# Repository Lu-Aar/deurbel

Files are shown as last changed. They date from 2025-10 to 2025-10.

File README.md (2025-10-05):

# deurbel
Making an ordinairy doorbell smart by having a notification through discord and ringing a klikaanklikuit chime.

When the doorbell is pressed there are three notifications:
- A mechanical chime
- A KlikAanKlikUit chime
- A Discord notification

There are also two extra inputs:
- A test button: Added to to test the doorbell functionality
- A mute switch: This can enable/disable the chimes

This project is fully designed in RUST no_std and it's designed to be used with a ESP32-WROOM-32.

## ToDo after clone
When this repo is cloned there is one step which has to be done before the code can be used.
Inside the bin folder the following file needs to be created:
global/mod.rs

This file should contain the following items:
``` rust
pub const WIFI_SSID: &str = "THE_SSID_TO_CONNECT_TO";
pub const WIFI_PASSWORD: &str = "THE_PASSWORD_OF_THE_SSID";
pub const DISCORD_WEBHOOK_URL: &str = "THE_URL_OF_THE_DISCORD_WEBHOOK_TO_USE";
pub const DISCORD_TTS: &str = false; // Set to true when to use Text To Speech
```

## PCB
The PCB was created in KiCad. It's a free opensource program for creating schematics and PCB's.
https://www.kicad.org/

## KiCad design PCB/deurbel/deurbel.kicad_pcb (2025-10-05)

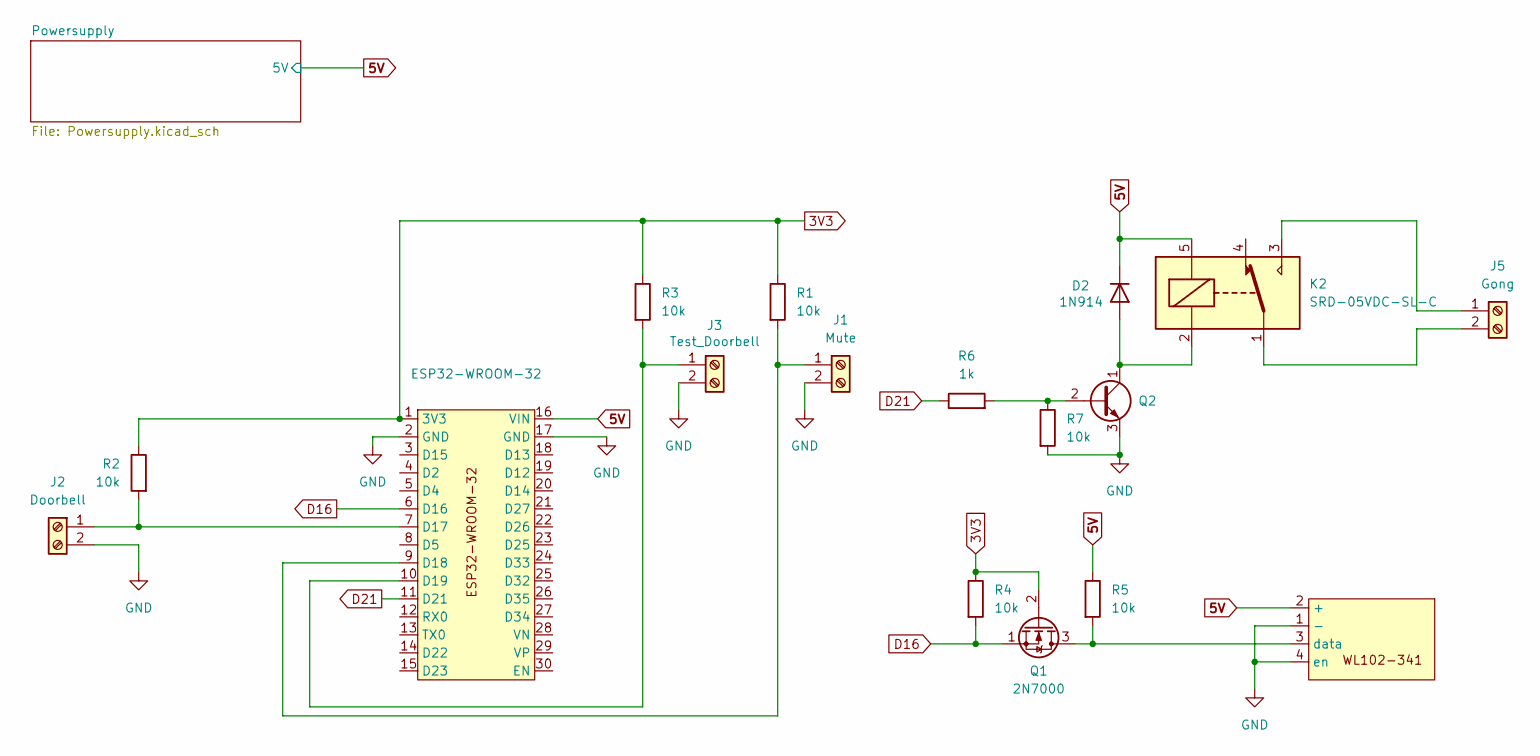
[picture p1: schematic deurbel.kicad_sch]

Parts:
D2: 1N914; D_DO-35_SOD27_P7.62mm_Horizontal
ESP32-WROOM-32: ESP32-WROOM-32
J1: Mute; TerminalBlock_Xinya_XY308-2.54-2P_1x02_P2.54mm_Horizontal
J2: Doorbell; TerminalBlock_Xinya_XY308-2.54-2P_1x02_P2.54mm_Horizontal
J3: Test_Doorbell; TerminalBlock_Xinya_XY308-2.54-2P_1x02_P2.54mm_Horizontal
J5: Gong; TerminalBlock_Xinya_XY308-2.54-2P_1x02_P2.54mm_Horizontal
K2: SRD-05VDC-SL-C; Relay_SPDT_SANYOU_SRD_Series_Form_C
Q1: 2N7000; TO-92_Inline
Q2: BC338; TO-92_Inline
R1, R2, R3, R4, R5, R7: 10k; R_Axial_DIN0204_L3.6mm_D1.6mm_P5.08mm_Horizontal
R6: 1k; R_Axial_DIN0204_L3.6mm_D1.6mm_P5.08mm_Horizontal
WL102-1: WL102-341

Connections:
3V3: ESP32-WROOM-32.1 (3V3), Q1.2 (G), R1.1, R2.1, R3.1, R4.1
5V: D2.1 (K), ESP32-WROOM-32.16 (VIN), K2.5, R5.1, WL102-1.2 (+); also elsewhere on the board
D16: ESP32-WROOM-32.6 (D16), Q1.1 (S), R4.2
D21: ESP32-WROOM-32.11 (D21), R6.1
GND: ESP32-WROOM-32.2 (GND), ESP32-WROOM-32.17 (GND), J1.2, J2.2, J3.2, Q2.3 (E), R7.2, WL102-1.1 (-), WL102-1.4 (en); also elsewhere on the board
unnamed: D2.2 (A), K2.2, Q2.1 (C)
unnamed: ESP32-WROOM-32.7 (D17), J2.1, R2.2
unnamed: ESP32-WROOM-32.9 (D18), J1.1, R1.2
unnamed: ESP32-WROOM-32.10 (D19), J3.1, R3.2
unnamed: J5.1, K2.3
unnamed: J5.2, K2.1
unnamed: Q1.3 (D), R5.2, WL102-1.3 (data)
unnamed: Q2.2 (B), R6.2, R7.1

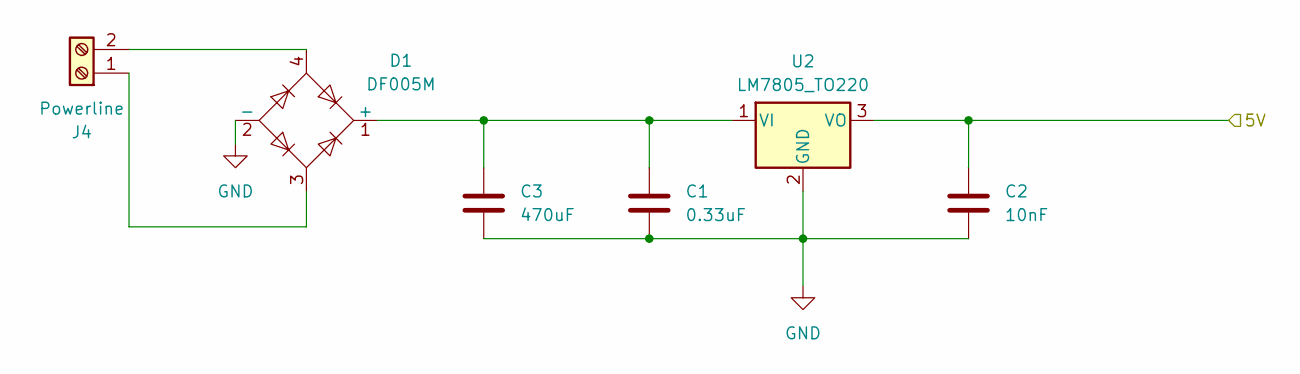
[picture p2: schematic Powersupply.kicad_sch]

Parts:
C1: 0.33uF; C_Disc_D4.3mm_W1.9mm_P5.00mm
C2: 10nF; C_Disc_D4.3mm_W1.9mm_P5.00mm
C3: 470uF; C_Disc_D4.3mm_W1.9mm_P5.00mm
D1: DF005M; Diode_Bridge_DIP-4_W7.62mm_P5.08mm
J4: Powerline; TerminalBlock_Xinya_XY308-2.54-2P_1x02_P2.54mm_Horizontal
U2: LM7805_TO220; TO-220-3_Vertical

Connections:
5V: C2.1, U2.3 (VO); also elsewhere on the board
GND: C1.2, C2.2, C3.2, D1.2 (-), U2.2 (GND); also elsewhere on the board
unnamed: C1.1, C3.1, D1.1 (+), U2.1 (VI)
unnamed: D1.3, J4.1
unnamed: D1.4, J4.2

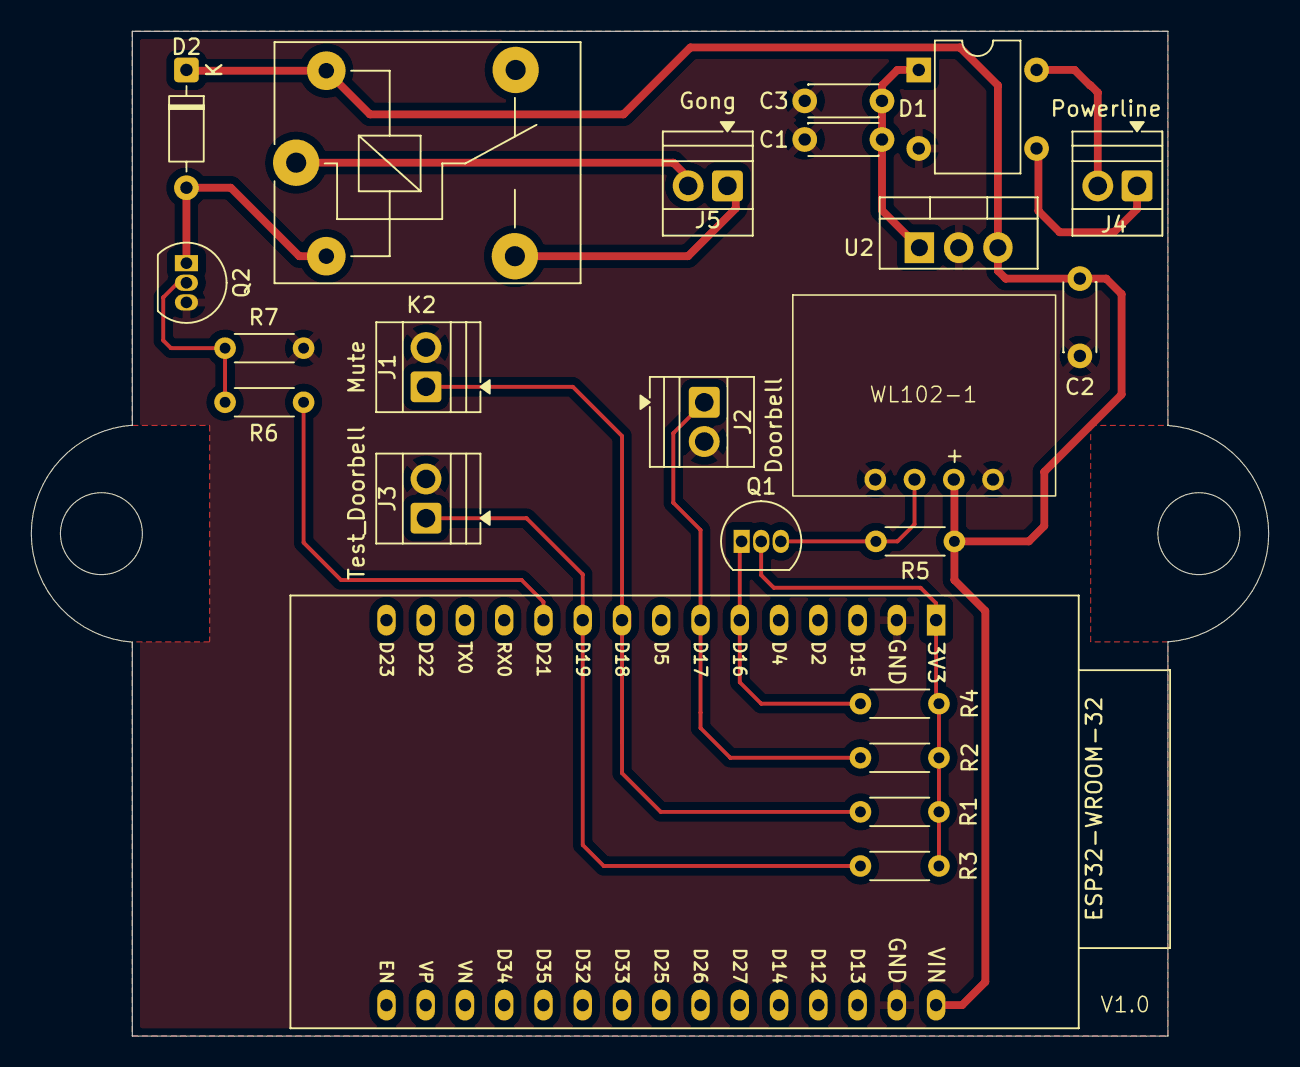
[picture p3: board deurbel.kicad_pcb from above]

Board: 2 copper layers, 80.1 x 65.0 mm, 23 parts (0 on the bottom side), 16 nets.

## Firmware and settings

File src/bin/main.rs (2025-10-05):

#![no_std]
#![no_main]
#![deny(
    clippy::mem_forget,
    reason = "mem::forget is generally not safe to do with esp_hal types, especially those \
    holding buffers for the duration of a data transfer."
)]
#![allow(static_mut_refs)]
#![feature(impl_trait_in_assoc_type)]

mod gong_control;
mod discord;
mod global;
mod notifications;
mod pin_state;

use gong_control::Gongcontrol;
use discord::Discord;
use global::{
    WIFI_SSID,
    WIFI_PASSWORD,
};
use notifications::NOTIFICATIONS;
use pin_state::PinState;

use log::info;
use esp_hal::{
    clock::CpuClock,
    delay,
    gpio::{
        Input,
        InputConfig,
        Pull,
        Level,
        Output,
        OutputConfig
    },
    peripherals::{RSA, SHA},
    rng::Rng,
    timer::timg::TimerGroup
};
use esp_wifi::{
    init,
    wifi::{
        WifiController,
        ClientConfiguration,
        Configuration,
        WifiState,
        WifiDevice,
        WifiEvent
    },
    EspWifiController
};
use embassy_net::{
    DhcpConfig,
    StackResources,
    Runner,
    Stack
};
use embassy_time::{
    Timer,
    Duration
};
use embassy_executor::Spawner;
use heapless::String;


#[panic_handler]
fn panic(_: &core::panic::PanicInfo) -> ! {
    loop {}
}


macro_rules! mk_static {
    ($t:ty,$val:expr) => {{
        static STATIC_CELL: static_cell::StaticCell<$t> = static_cell::StaticCell::new();
        #[deny(unused_attributes)]
        let x = STATIC_CELL.uninit().write(($val));
        x
    }}
}

extern crate alloc;

// This creates a default app-descriptor required by the esp-idf bootloader.
// For more information see: <https://docs.espressif.com/projects/esp-idf/en/stable/esp32/api-reference/system/app_image_format.html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>
esp_bootloader_esp_idf::esp_app_desc!();

#[esp_hal_embassy::main]
async fn main(spawner: Spawner) -> ! {
    let (ios, stack, rsa_sha, mut rng) = initialize(spawner).await;
    let (data_pin, bell, mute, test_bell, mut physical_gong) = ios;
    let mut gong = Gongcontrol::new(37877946, 251, data_pin);

    let delay = delay::Delay::new();
    let mut discord = Discord::new(stack, rsa_sha);

    let mut bell = PinState::new(bell);
    let mut test_bell = PinState::new(test_bell);
    let mut mute = PinState::new(mute);

    loop {
        if bell.falling_edge() || test_bell.falling_edge()
        {
            let _ = discord.send_message(NOTIFICATIONS[rng.random() as usize % NOTIFICATIONS.len()]).await;
            if mute.is_high()
            {
                physical_gong.set_high();
                gong.ring();
                physical_gong.set_low();
            }
            info!("ding dong!");
            delay.delay_millis(1000);
        }
        else {
            delay.delay_millis(50);
        }
    }
}

async fn initialize(spawner: Spawner) -> ((Output<'static>, Input<'static>, Input<'static>, Input<'static>, Output<'static>),
                                            Stack<'static>,
                                            (RSA<'static>, SHA<'static>),
                                            Rng) {
    esp_println::logger::init_logger_from_env();

    let config = esp_hal::Config::default().with_cpu_clock(CpuClock::max());
    let peripherals = esp_hal::init(config);

    esp_alloc::heap_allocator!(size: 128 * 1024);

    let timg0 = TimerGroup::new(peripherals.TIMG0);
    let mut rng = Rng::new(peripherals.RNG);

    let esp_wifi_ctrl = &*mk_static!(
        EspWifiController<'static>,
        init(timg0.timer0, rng.clone(), peripherals.RADIO_CLK).unwrap()
    );

    let (controller, interfaces) = esp_wifi::wifi::new(&esp_wifi_ctrl, peripherals.WIFI).unwrap();

    let wifi_interface = interfaces.sta;

    let timg1 = TimerGroup::new(peripherals.TIMG1);
    esp_hal_embassy::init(timg1.timer0);

    let mut dhcp_config = DhcpConfig::default();
    let host_name: String<32> = String::try_from("deurbel").unwrap();
    dhcp_config.hostname = Some(host_name);

    let config = embassy_net::Config::dhcpv4(dhcp_config);

    let seed = (rng.random() as u64) << 32 | rng.random() as u64;

    let (stack, runner) = embassy_net::new(
        wifi_interface, 
        config, 
        mk_static!(StackResources<3>, StackResources::<3>::new()), 
        seed
    );

    spawner.spawn(connection(controller)).ok();
    spawner.spawn(net_task(runner)).ok();

    loop {
        if stack.is_link_up() {
            break;
        }
        Timer::after(Duration::from_millis(500)).await;
    }

    loop {
        if let Some(config) = stack.config_v4() {
            info!("IP address: {}", config.address);
            break;
        }
        Timer::after(Duration::from_millis(500)).await;
    }

    let gpio16_out = Output::new(peripherals.GPIO16, Level::Low, OutputConfig::default());
    let gpio17_in = Input::new(peripherals.GPIO17, InputConfig::default()); 
    let gpio18_in = Input::new(peripherals.GPIO18, InputConfig::default());
    let gpio19_in = Input::new(peripherals.GPIO19, InputConfig::default());
    let gpio21_out = Output::new(peripherals.GPIO21, Level::Low, OutputConfig::default());

    ((gpio16_out, gpio17_in, gpio18_in, gpio19_in, gpio21_out), stack, (peripherals.RSA, peripherals.SHA), rng)
}

#[embassy_executor::task]
async fn net_task(mut runner: Runner<'static, WifiDevice<'static>>) {
    runner.run().await;
}

#[embassy_executor::task]
async fn connection(mut controller: WifiController<'static>) {
    info!("Start connection task");
    info!("Device capabilities: {:?}", controller.capabilities());

    loop {
        match esp_wifi::wifi::wifi_state() {
            WifiState::StaConnected => {
                controller.wait_for_event(WifiEvent::StaConnected).await;
                Timer::after(Duration::from_millis(5000)).await;
            }
            _ =>{}
        }

        if !matches!(controller.is_started(), Ok(true)) {
            let client_config = Configuration::Client(ClientConfiguration {
                ssid: WIFI_SSID.into(),
                password: WIFI_PASSWORD.into(),
                ..Default::default()
            });
            controller.set_configuration(&client_config).unwrap();
            info!("Starting wifi");
            controller.start_async().await.unwrap();
            info!("Wifi started!");

            info!("Scanning for networks...");
            let result = controller.scan_n_async(10).await.unwrap();
            for ap in result {
                info!("{:?}", ap);
            }
        }
        info!("About to connect to WiFi");

        match controller.connect_async().await {
            Ok(_) => info!("Connected to WiFi"),
            Err(e) => {
                info!("Failed to connect to wifi: {e:?}");
                Timer::after(Duration::from_millis(5000)).await;
            }
        }
    }
}

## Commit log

2025-07-13 After a lot of struggle the ESP32 can connect to WiFi. The next step is to be able to send to discord
2025-07-13 Commented out what is currently broken
2025-07-24 After a lot of trying finally got it working. The readme of the crate was wrong. The functionality has been updated without updating the readme... Could've saved me a lot of headache in looking throu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
    [main.rs]
2025-07-24 Added the buttons to trigger the doorbell
2025-08-15 Created a struct to check pin state
2025-08-15 Created a PCB for the doorbell. It's designed to fit inside a junction box
    [Powersupply.kicad_sch, deurbel.kicad_pcb, deurbel.kicad_sch]
